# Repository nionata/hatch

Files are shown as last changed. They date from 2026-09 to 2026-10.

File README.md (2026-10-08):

# hatch

## BOM

* [esp32 classic: dual-core xtensa](https://www.amazon.com/dp/B08D5ZD528?plpRedirect=mhFallback&th=1)
* [WS2811 5V x 50 LED](https://www.amazon.com/gp/product/B01AG923GI/ref=ppx_yo_dt_b_search_asin_title?ie=UTF8&th=1)
* [power supply (5v, 5a, 25w)](https://www.amazon.com/5-5x2-5mm-Industrial-Controllers-5-5x2-1mm-Compatible/dp/B0FDRSWL8T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)

## Firmware

Leveraging the [WLED](https://kno.wled.ge) project for controls. Flashed via the WLED web installer. Configured for WS281x RGB, 50 LEDs, data on GPIO 4.

The firmware in this repo was used for initial board bring-up and prototyping.

## Development

The project started on a breadboard. I wanted to verify the ESP32 classic that has been in my electronics box for ~5 years worked. The first step was bringing the board up and turning on a single LED. The board and LED strip were powered by the USB cable at this point. The next step was bringing in a power supply. I used a star pattern out of a barrel terminal jack to power the LED strip and the board. The 3.3v digital logic signal drove the LED strip's data line. This worked across all 50 LEDs in the strip.

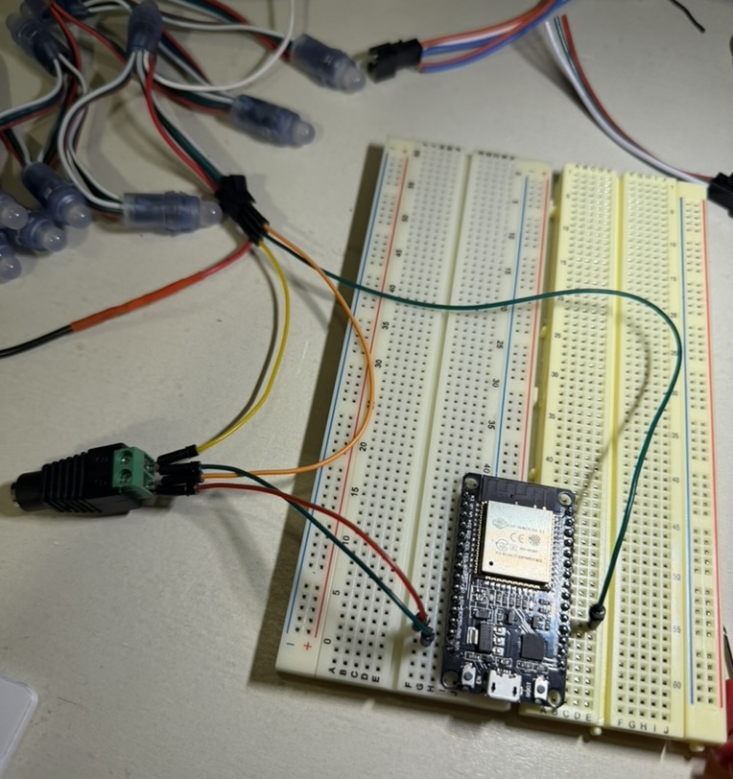
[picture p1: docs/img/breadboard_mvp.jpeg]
Breadboard MVP


The 3D-printed enclosure came next. There is access to the USB port in the rear. THe front has a panel-mounted barrel jack for power and hole for the JST-SM 3-pin LED cable. The tolerances on all of these openings could be better, but it got the job done. There are little standoffs for the PCB to sit on. The lid has nice rails to self-align with the screw posts.

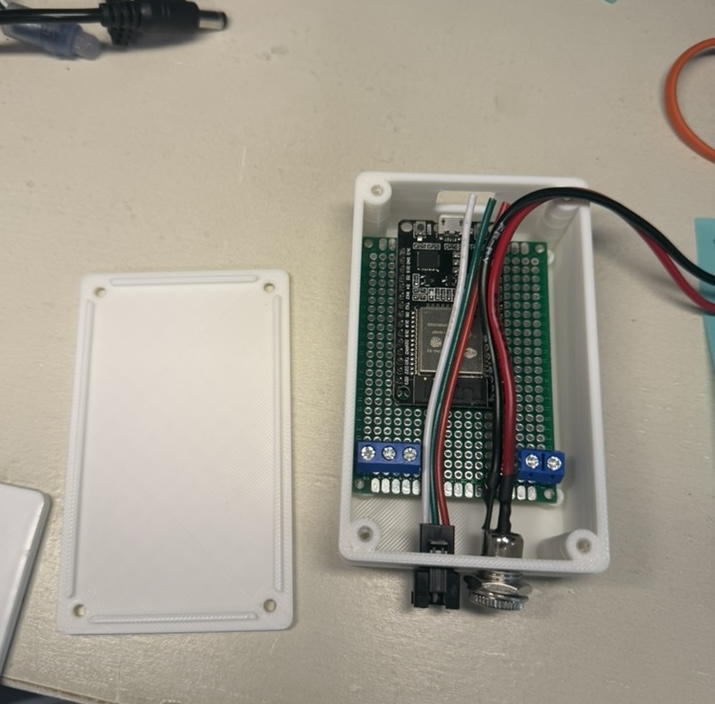
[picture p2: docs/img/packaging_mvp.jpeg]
Packaging MVP


It was then time to solder the circuit down to the protoboard. I decided on simple screw terminals for input power and output power and data. I routed everything on the bottom of the board.

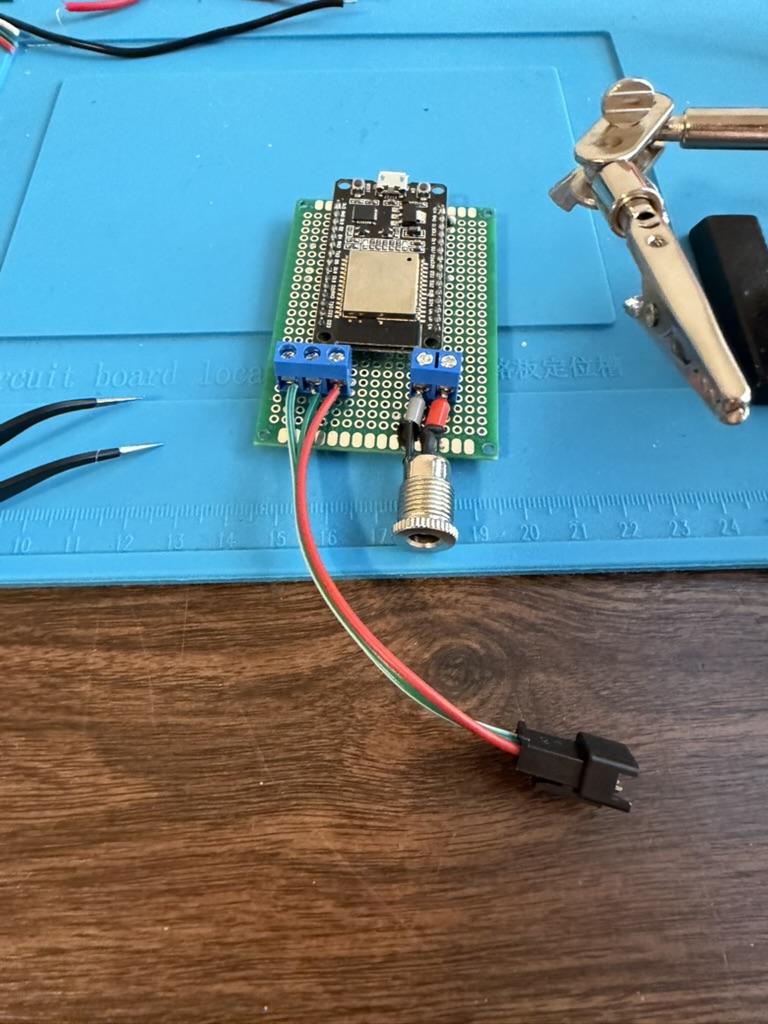
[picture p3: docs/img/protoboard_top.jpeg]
Protoboard Top
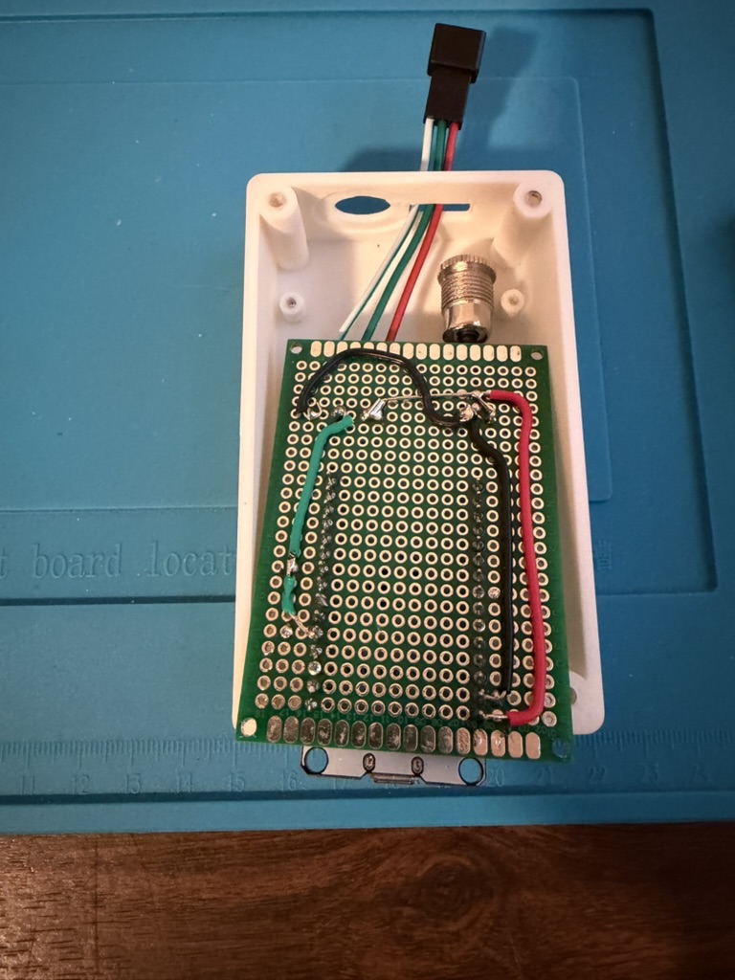
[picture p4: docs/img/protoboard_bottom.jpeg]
Protoboard Bottom
 

Then the first integration test. All 50 pixels were driven to a bright green. The board worked as expected.

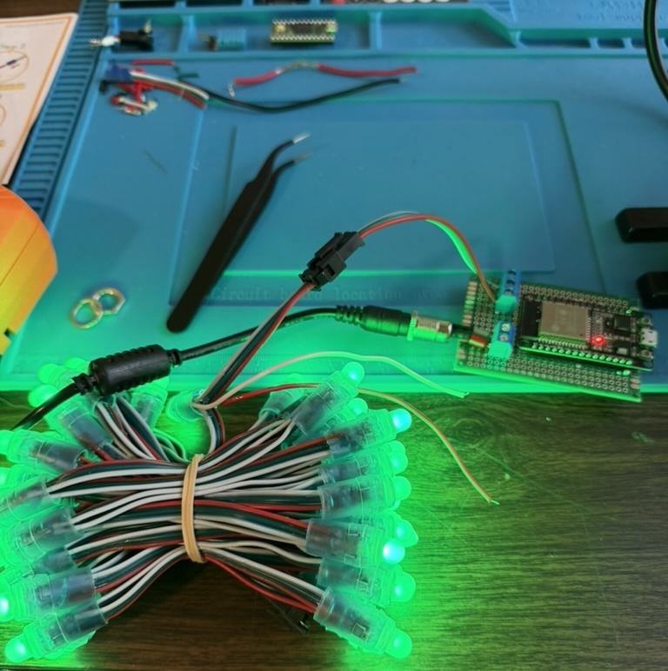
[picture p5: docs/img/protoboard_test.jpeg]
Protoboard Test


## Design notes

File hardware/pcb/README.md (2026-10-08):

# PCB

* 5cm x 7cm protoboard
* 2pin screw terminal - Row E, Col 4&6
* 3pin screw terminal - Row E, Col
* 22 awg solid copper tinned wire

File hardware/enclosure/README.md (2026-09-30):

# Enclosure

## Dimensions

* Barrel connector
  * 9.77mm barrel plug diameter
  * 2.02mm panel flange width
  * 13.7mm nut width
* JST SM
  * 7.47mm height
  * 10.47mm width
  * 8.11mm panel flange width
* Proto board ("5x7cm")
  * 68.68mm l
  * 48.70mm w
  * 2mm from center of screw hole to side of board
* Micro USB
  * 8.03mm width
  * 2.95mm height
* ESP32
  * mounted on proto board from columns D5 to D15 and rows H through X

## v0

Things to fix:
- [x] The wiring is way too tight. Add l and w to the enclosure
- [ ] The protoboard w seems good as i can get both standoff screws in. however, the length is off. The product page says 5x7cm.
- [ ] Lid screws were a bit tough to get in. Increase the inner diameter a bit.
- [ ] JST has plenty of room. Could tighten. Or design a shim to add later
- [ ] Barrel connector nut cutout can be made a lot smaller
- [ ] Barrel connector hole can be made smaller
- [ ] Micro usb is too big and offset.
    - [ ] Move it down and 1 proto pin right
    - [ ] Move board back to panel mount the micro - 2/16" end gap
    - [ ] Make opening smaller. Connector is 3/16" x 7/16". however, if we panel mount we can fit the size of the micro

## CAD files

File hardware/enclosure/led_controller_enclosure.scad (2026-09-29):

// ============================================================
//  ESP32 LED controller enclosure (protoboard, barrel in, JST out)
//  Units: mm.  Render F6, export STL per part (see `part`).
//
//  Layout (top view, X to the right):
//   -X wall : barrel power jack + JST cable slot  (terminal-block end)
//   +X wall : micro-USB opening                   (ESP32 end)
//   Board sits on 4 M2 standoffs; lid held by 4 M3 corner posts.
//
//  Everything marked  ** MEASURE **  is an estimate: check it
//  against your parts and tweak before printing.
// ============================================================

in = 25.4;
$fn = 48;

/* [Which part to output] */
// "print"   = box + lid laid out for printing (lid flipped)
// "box"     = box only, "lid" = lid only
// "preview" = assembled view with ghost board, lid lifted
part = "print";

/* [Protoboard] */
board_l          = 69.85;       // X length (69.85)
board_w          = 50.8;        // Y width  (50.8)
board_t          = 1.6;
board_hole_inset = 2.5;         // ** MEASURE ** corner hole center from board edges
comp_h           = 15.875;    // tallest thing above board top (headers/terminal screws)

/* [Board standoffs (M2)] */
standoff_h          = 7;    // room for solder joints + wiring UNDER the board
standoff_od         = 5;
standoff_hole_d     = 1.8;  // pilot for self-tapping M2 in PETG (use ~3.2 for M2 heat-set insert)
standoff_hole_depth = 7.5;  // fits M2x8 (M2x6 also fine)

/* [Enclosure shell] */
wall        = 2.4;
floor_t     = 2.4;
corner_r    = 3;
top_clear   = 2;      // air gap above tallest component
term_gap    = 14;     // board edge -> -X wall: wire bend room for terminal blocks
end_gap     = 8;      // board edge -> +X wall: needed so the corner lid posts clear the board
side_gap    = 1.5;    // board edge -> long walls

/* [Lid + lid screws (M3 flush / countersunk)] */
lid_t           = 3;
lip_h           = 2;
lip_t           = 1.6;
lip_tol         = 0.3;   // lip clearance to inner wall
post_od         = 7.5;
use_heat_set    = false; // false: M3 threads directly into printed post
post_hole_self  = 2.6;   // M3 self-tap in PETG
post_hole_insert= 4.2;   // M3 heat-set insert
post_hole_depth = 10;    // use M3 x 12 (3 lid + ~9 into post)
lid_hole_clear  = 3.4;
csk_d           = 6.4;   // countersink dia for flush head ** MEASURE head **

/* [Barrel panel-mount jack (-X wall)] */
barrel_d             = 11.1;  // 7/16" max thread dia
barrel_clear         = 0.4;
barrel_thread_len    = 1.6;   // 1/16": wall must be <= this at the jack
barrel_flange        = 1.6;   // 1/16" flange radius past thread (sits on outside face)
barrel_nut_pocket_d  = 20;    // inside-face pocket that thins wall to thread length
barrel_y             = 19;    // from inner wall (interior Y)
barrel_z_above_board = 5.5;   // jack center above board top

/* [JST-SM output cable slot (-X wall)] */
// Slot is sized so a crimped JST-SM housing can pass through
jst_slot_w           = 13;
jst_slot_h           = 8;
jst_z_above_board    = 5;

/* [Micro-USB opening (+X wall)] */
usb_w            = 15;
usb_h            = 10.5;
usb_z_above_board= 8;    // ** MEASURE ** USB center above board top (depends on header height)
usb_y_offset     = 0;    // shift if ESP32 isn't centered across the board

// ---------------- derived ----------------
int_l   = term_gap + board_l + end_gap;
int_w   = board_w + 2 * side_gap;
int_h   = standoff_h + board_t + comp_h + top_clear;
outer_l = int_l + 2 * wall;
outer_w = int_w + 2 * wall;
box_h   = floor_t + int_h;

bx = term_gap;   // board origin in interior coords
by = side_gap;

pin = post_od / 2 - 0.5;   // post centers overlap the walls slightly
post_pts = [[pin, pin], [int_l - pin, pin],
            [pin, int_w - pin], [int_l - pin, int_w - pin]];

standoff_pts = [
  [bx + board_hole_inset,           by + board_hole_inset],
  [bx + board_l - board_hole_inset, by + board_hole_inset],
  [bx + board_hole_inset,           by + board_w - board_hole_inset],
  [bx + board_l - board_hole_inset, by + board_w - board_hole_inset]];

// ---------------- helpers ----------------
module rbox(l, w, h, r) {
  hull() for (x = [r, l - r], y = [r, w - r])
    translate([x, y, 0]) cylinder(r = r, h = h);
}

// rounded slot cut along +X, centered on y,z = 0, from x=0 to len
module rslot_x(w, h, r, len) {
  hull() for (sy = [-1, 1], sz = [-1, 1])
    translate([0, sy * (w / 2 - r), sz * (h / 2 - r)])
      rotate([0, 90, 0]) cylinder(r = r, h = len);
}

// ---------------- box ----------------
module box() {
  post_hole = use_heat_set ? post_hole_insert : post_hole_self;
  z_board_top = floor_t + standoff_h + board_t;   // outer coords

  difference() {
    union() {
      difference() {
        rbox(outer_l, outer_w, box_h, corner_r);
        translate([wall, wall, floor_t]) cube([int_l, int_w, int_h + 1]);
      }
      // posts + standoffs (interior coords -> outer)
      translate([wall, wall, floor_t]) {
        for (p = post_pts) translate([p[0], p[1], 0]) cylinder(d = post_od, h = int_h);
        for (p = standoff_pts) translate([p[0], p[1], 0]) cylinder(d = standoff_od, h = standoff_h);
      }
    }

    // lid screw holes
    translate([wall, wall, floor_t])
      for (p = post_pts)
        translate([p[0], p[1], int_h - post_hole_depth]) cylinder(d = post_hole, h = post_hole_depth + 1);

    // M2 standoff pilot holes (extend slightly into floor)
    translate([wall, wall, floor_t])
      for (p = standoff_pts)
        translate([p[0], p[1], standoff_h - standoff_hole_depth]) cylinder(d = standoff_hole_d, h = standoff_hole_depth + 1);

    // barrel jack: through hole + inside pocket thinning wall to thread length
    translate([-1, wall + barrel_y, z_board_top + barrel_z_above_board]) {
      rotate([0, 90, 0]) cylinder(d = barrel_d + barrel_clear, h = wall + 2);
    }
    translate([barrel_thread_len, wall + barrel_y, z_board_top + barrel_z_above_board])
      rotate([0, 90, 0]) cylinder(d = barrel_nut_pocket_d, h = wall - barrel_thread_len);

    // JST cable slot
    translate([-1, wall + int_w - barrel_y, z_board_top + jst_z_above_board])
      rslot_x(jst_slot_w, jst_slot_h, 1.5, wall + 2);

    // micro-USB opening
    translate([wall + int_l - 1, wall + int_w / 2 + usb_y_offset, z_board_top + usb_z_above_board])
      rslot_x(usb_w, usb_h, 2, wall + 2);
  }
}

// ---------------- lid ----------------
// Installed orientation: plate z in [0, lid_t], lip hangs below (z<0).
module lid() {
  ci = int_l - 2 * lip_tol;
  cw = int_w - 2 * lip_tol;
  csk_depth = (csk_d - lid_hole_clear) / 2;

  difference() {
    union() {
      rbox(outer_l, outer_w, lid_t, corner_r);
      translate([wall + lip_tol, wall + lip_tol, -lip_h])
        difference() {
          cube([ci, cw, lip_h + 0.01]);
          translate([lip_t, lip_t, -1]) cube([ci - 2 * lip_t, cw - 2 * lip_t, lip_h + 2]);
        }
    }
    for (p = post_pts) translate([wall + p[0], wall + p[1], 0]) {
      translate([0, 0, -lip_h - 1]) cylinder(d = lid_hole_clear, h = lid_t + lip_h + 2);
      translate([0, 0, lid_t - csk_depth]) cylinder(d1 = lid_hole_clear, d2 = csk_d + 0.02, h = csk_depth + 0.01);
      // notch the lip around the corner posts
      translate([0, 0, -lip_h - 1]) cylinder(r = post_od / 2 + 0.3, h = lip_h + 1);
    }
  }
}

// ---------------- preview ghosts ----------------
module ghost() {
  translate([wall + bx, wall + by, floor_t + standoff_h]) {
    color("green", 0.5) cube([board_l, board_w, board_t]);
    color("red", 0.15) translate([0, 0, board_t]) cube([board_l, board_w, comp_h]);
    // ESP32 USB end overhang
    color("blue", 0.4) translate([board_l, board_w / 2 - 4 + usb_y_offset, board_t + usb_z_above_board - 2])
      cube([1/8 * in, 8, 4]);
  }
}

// ---------------- output ----------------
if (part == "box") box();
else if (part == "lid") translate([0, 0, lid_t]) rotate([180, 0, 0]) translate([0, -outer_w, 0]) lid();
else if (part == "preview") {
  box();
  ghost();
  translate([0, 0, box_h + 12]) lid();
} else {
  box();
  // lid flipped (lip up, countersinks on the bed), placed beside the box
  translate([0, -10, lid_t]) rotate([180, 0, 0]) lid();
}

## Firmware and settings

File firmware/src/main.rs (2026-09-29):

#![no_std]
#![no_main]

use esp_backtrace as _;
esp_bootloader_esp_idf::esp_app_desc!();
use esp_hal::{delay::Delay, rmt::Rmt, time::Rate};
use esp_hal_smartled::{buffer_size, color_order, RmtSmartLeds, WS2811_LOW_SPEED_TIMING};
use smart_leds::{SmartLedsWrite, RGB8};

const NUM_LEDS: usize = 50; // adjust to match your strip length

#[esp_hal::main]
fn main() -> ! {
    let peripherals = esp_hal::init(esp_hal::Config::default());
    let delay = Delay::new();

    let freq = Rate::from_mhz(80);
    let rmt = Rmt::new(peripherals.RMT, freq).unwrap();

    // WS2811 on GPIO4. RGB color order. Drive all LEDs to clear the power-on state.
    let mut led: RmtSmartLeds<{ buffer_size::<RGB8>(NUM_LEDS) }, _, RGB8, color_order::Rgb> =
        RmtSmartLeds::new(
            WS2811_LOW_SPEED_TIMING,
            rmt.channel0,
            peripherals.GPIO4,
            freq,
        )
        .unwrap();

    loop {
        let colors = [RGB8::new(0, 100, 0); NUM_LEDS];
        let brightness = 255;
        let b = smart_leds::brightness(colors.iter().copied(), brightness);
        let _ = led.write(b);
        delay.delay_millis(1000u32);
    }
}

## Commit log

2026-09-22 No std with LEDs
2026-09-29 Test lighting all LEDs
2026-09-29 Enclosure box v0
    [led_controller_enclosure.scad]
2026-09-29 Add more space around board
2026-09-29 Fix board parameters
    [led_controller_enclosure.scad]
2026-09-29 Fix board length param
    [led_controller_enclosure.scad]
2026-09-29 Ignore 3d printing files
2026-10-08 Add pcb notes
